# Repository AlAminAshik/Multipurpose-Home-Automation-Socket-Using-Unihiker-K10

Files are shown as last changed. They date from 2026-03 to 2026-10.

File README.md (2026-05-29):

# Multipurpose-Home-Automation-Socket-Using-Unihiker-K10
This repo contains all the coding and circuit diagram related to my home automation project using unihiker K10.

Important fix: I found a bug in the Unihikerk10.cpp code, for the readALS() function. It uses a ratio to calculate the light intensity (_ratio = _als_ch1/(_als_ch0+_als_ch1);) At complete darkness both ch0 and ch1 can become 0 and the ratio becomes 0/0 which causes device to reset. Fix is to add a number with the denominator (_ratio = _als_ch1/(_als_ch0+_als_ch1+1))



Imagine controlling your light, fan, alarm, and even AC using voice without the need for wifi or a phone.

In this project, I will describe in detail all the processes of making such a device. The 3d printed enclosure fits perfectly on the wall, and connecting to the outlet is super easy.

## The device currently features:
* Voice commands to perform various tasks. (with dual mic)
* Appliance control using TRIAC (1 Fan with dimmer, and 1 Light)
* Appliance control using Infra-Red (1 AC by cloning signal)
* Alarm clock page.
* Four touch sensitive buttons.
* A 2.8-inch color LCD screen.
* Wifi synced Clock.
* Temperature, Humidity, and Light Intensity Measurement.
* Auditory feedback.
* Mobile phone/webpage control (future implementation)

## Components used:
* 1 x UNIHIKER K10 AI Coding Board LINK
* 4 x Capacitive Touch Switch TTP223B LINK
* 4 x 15pF capacitors.
* 1 x USB Samsung adapter 5V 2A
* 1 x 5mm IR LED LINK
* 2 x BT134-600E 4A TRIAC
* 1 x MOV 471k LINK
* 2 x 275V 0.1uF suppression capacitor LINK
* 2 x 0.1uF 450V 104k LINK
* Some resistors and wires

# What it does?

I wanted to make a very practical project. With that in mind, I added multiple features. They are:

### Two Pages:
* Home page
    - shows time, WiFi, appliance status, light intensity, humidity, temperature, alarm time status.
    - Responds to the four buttons:
        - Alarm button:
            - short press: Switches between fan speeds (0 to 4), and stops the alarm if ringing.
            - long press: switches to the alarm page.
        - AC button:
            - short press: Toggles AC ON and OFF with a single press.
        - Fan button:
            - short press: Toggles Fan ON and OFF with a single press.
        - Light button:
            - short press: Toggles Light ON and OFF with a single press.
    - Responds to voice commands:
        - Voice command "Show Alarm": switches to the alarm page.
        - Voice command "Hide Alarm": switches to the main page.
        - Voice command "Fan" : Toggles fan ON and OFF.
        - Voice command "Lights": Toggles light ON and OFF.
        - Voice command "AC": Toggles AC ON and OFF.
        - Voice command "Fan Full speed": sets fan speed to max speed.
        - Voice command "Fan low speed": set the fan speed to the lowest speed.

* Alarm page (24 hour format)
    - shows time, WiFi, alarm logo, alarm time, alarm status, and button functions.
    - Responds to the four buttons:
        - Alarm button:
            - short press: stops the alarm if ringing.
            - long press: switches to the Home page.
        - AC button:
            - short press: Toggles alarm On and OFF.
        - Fan button:
            - short press: increments the minute hand.
        - Light button:
            - short press: increments the hour hand.
    - Responds to voice commands: Same as Home page.

# 3D Files
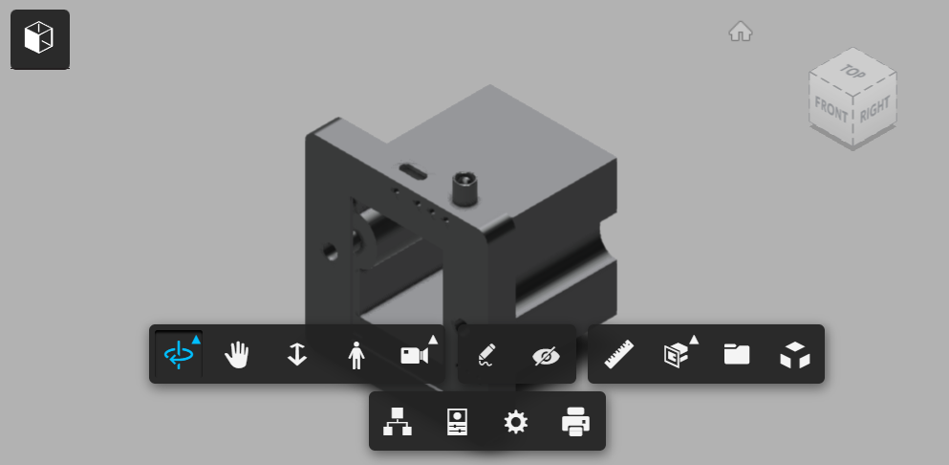
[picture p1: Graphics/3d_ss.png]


The 3d structure is made using Fusion360, you can get the file from this link: https://a360.co/4cmEmkP

# The code
The code is located at "Main Code/src/main.cpp". The code has some header file dependency that are located at "Main code/include".
[]Additional two file, the IRRecvDump.cpp code was used to find the raw infra red data from my AC remote control and IRSendBasic.cpp was used to generate and test if my AC properly responds to signal. These two files were not a part of the main code.

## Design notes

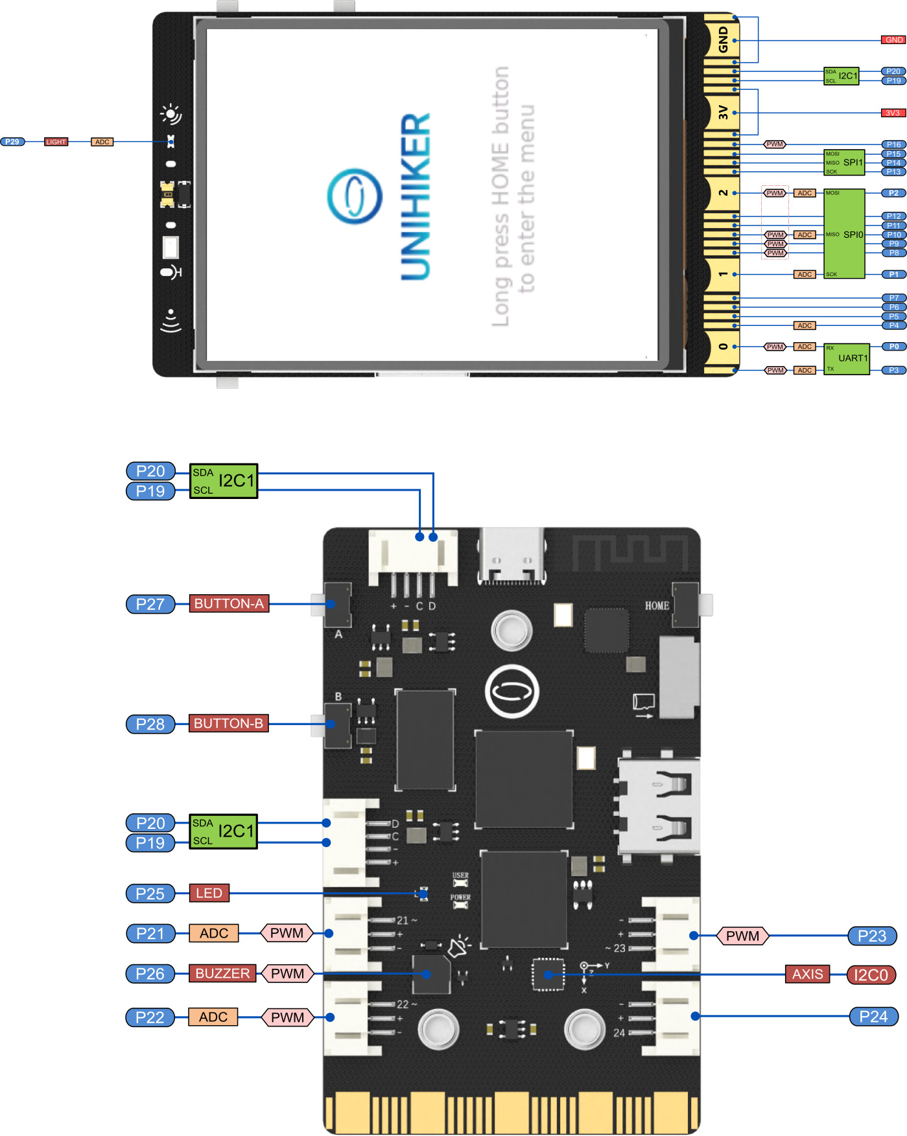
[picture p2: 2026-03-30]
UniHiker-pinout-diagram.jpg

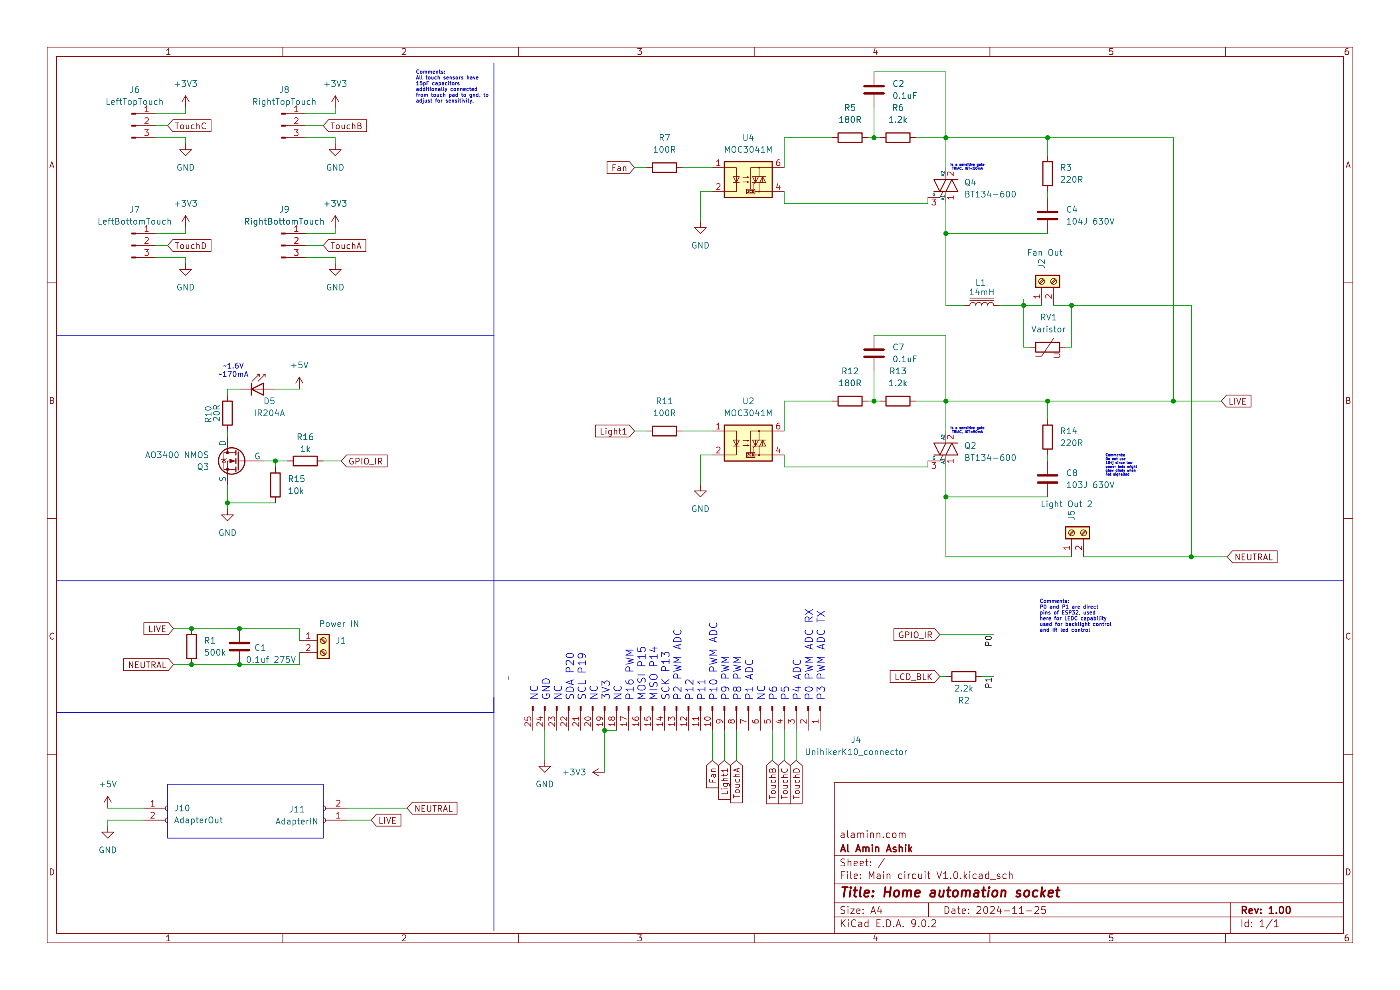
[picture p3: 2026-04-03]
circuit/Main circuit V1.0/Main circuit V1.0.png

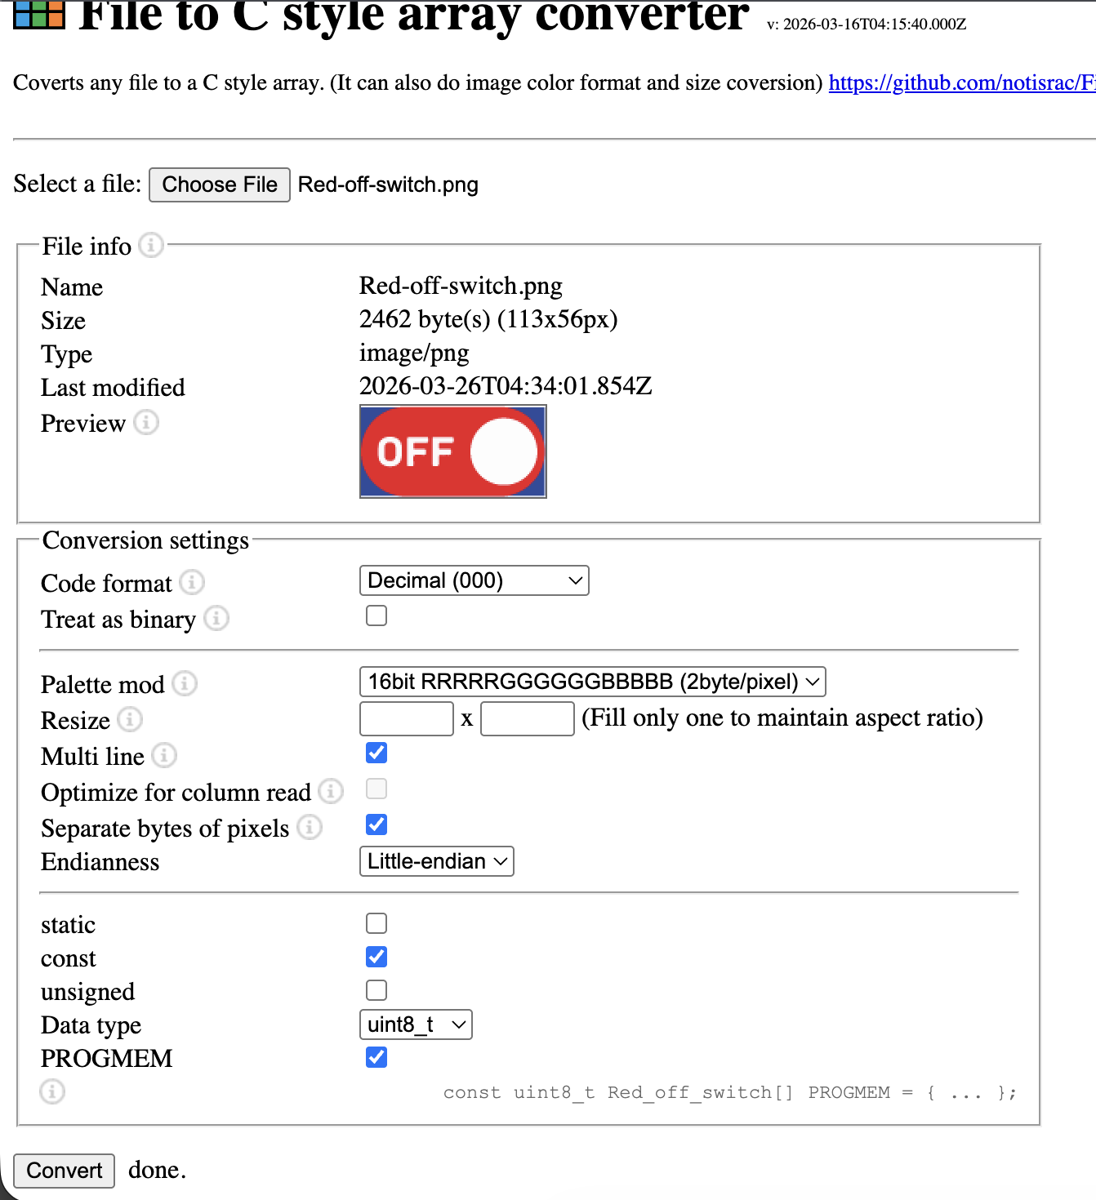
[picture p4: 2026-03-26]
Graphics/parameters to generate c code from image unihiker k10.png

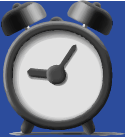
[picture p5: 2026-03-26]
Graphics/alarmclock.png

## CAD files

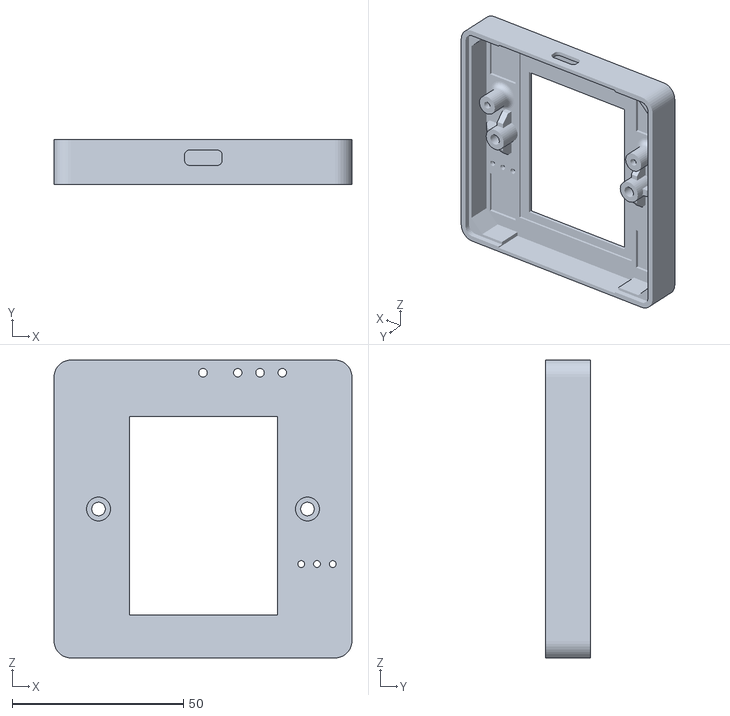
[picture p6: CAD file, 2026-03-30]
3D files/main body front.stl
87.0 x 13.0 x 87.0

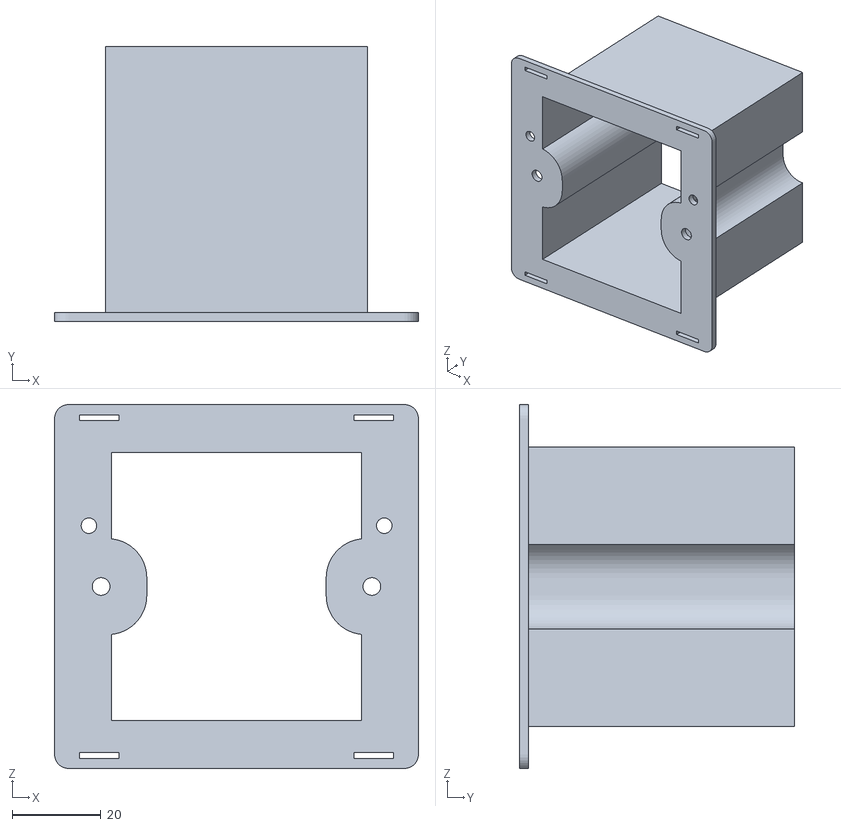
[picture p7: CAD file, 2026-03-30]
3D files/Main body body.stl
82.0 x 62.0 x 82.0

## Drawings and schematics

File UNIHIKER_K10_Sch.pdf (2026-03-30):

11

22

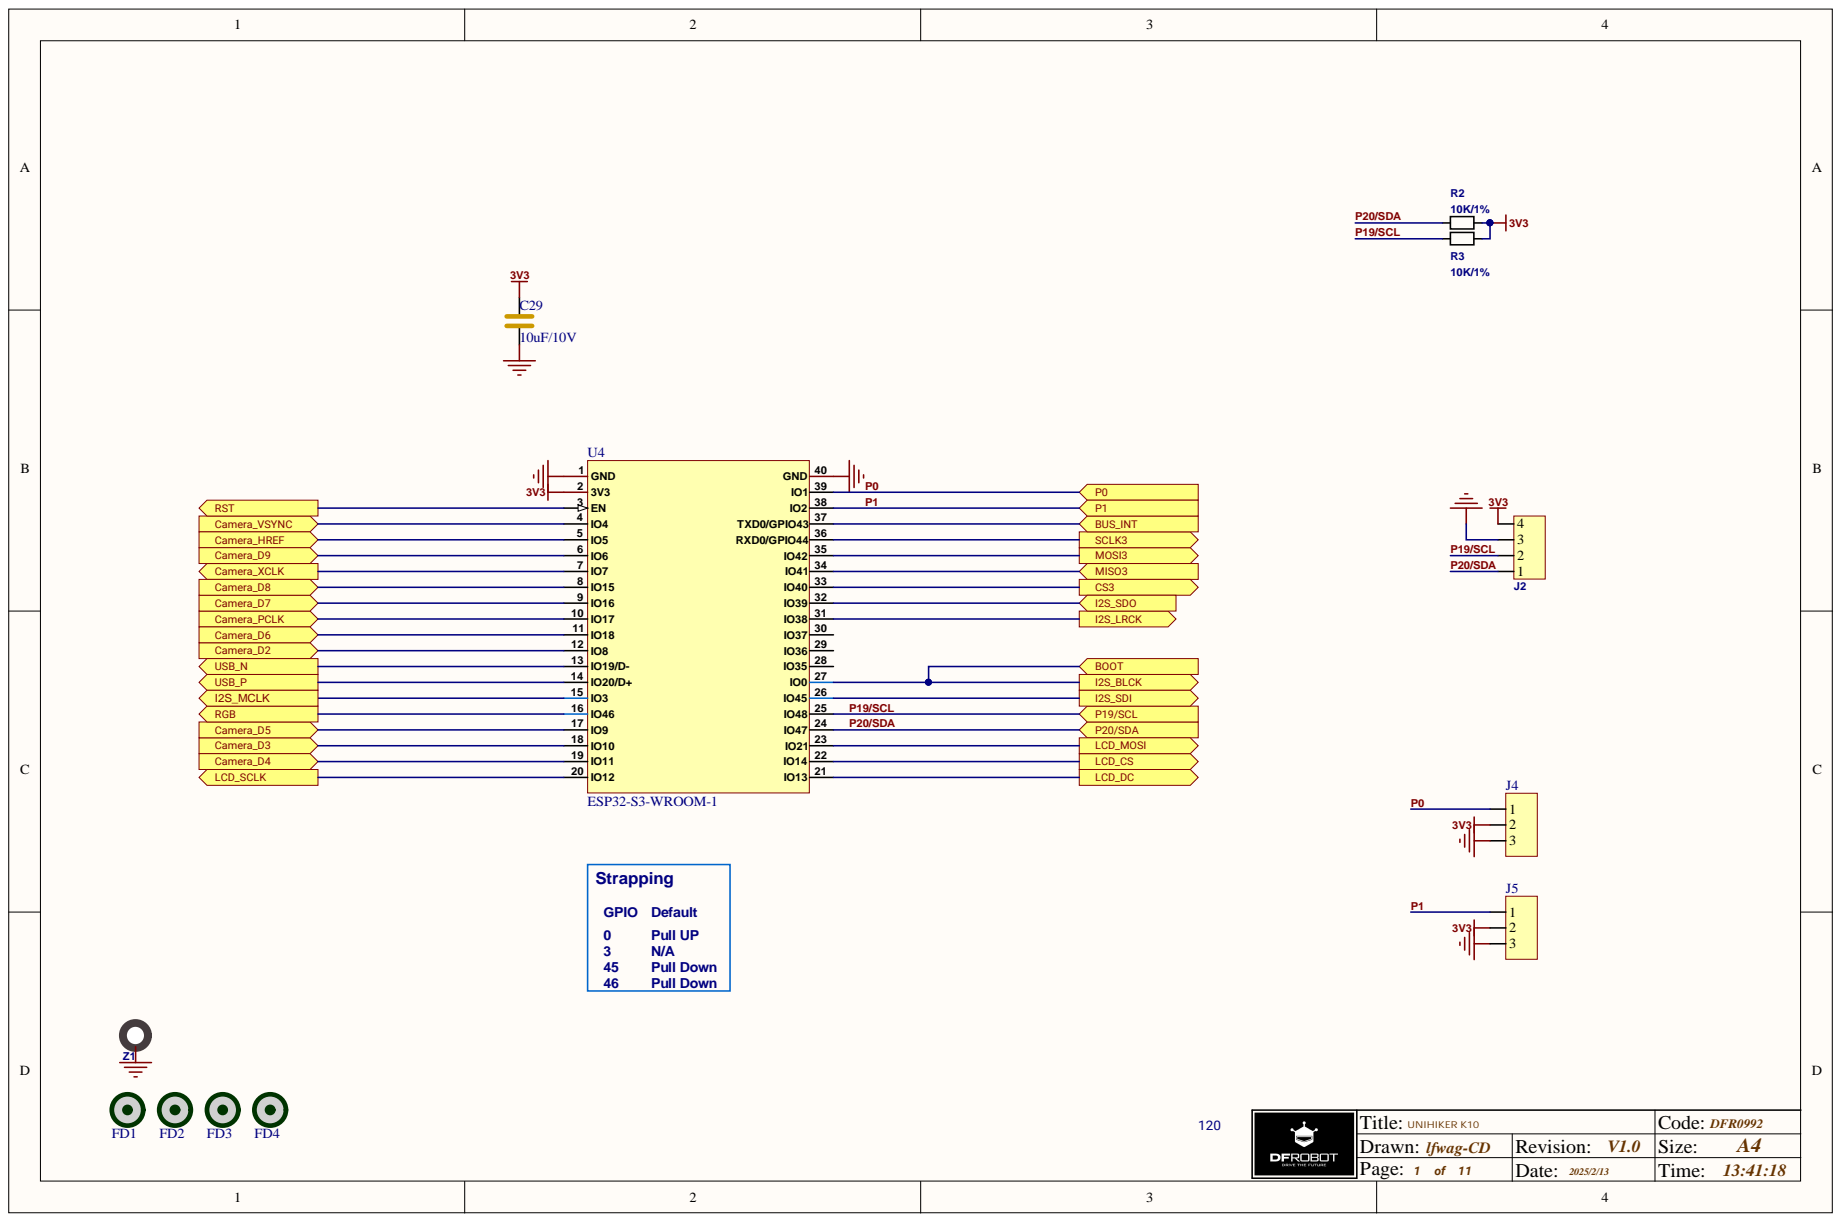
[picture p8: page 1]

A | A

## POP0

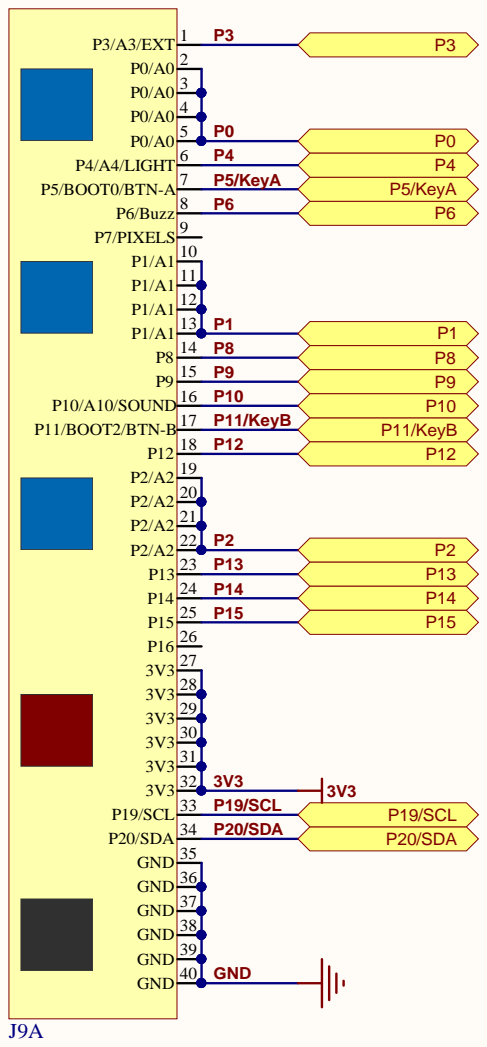
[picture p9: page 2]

11

22

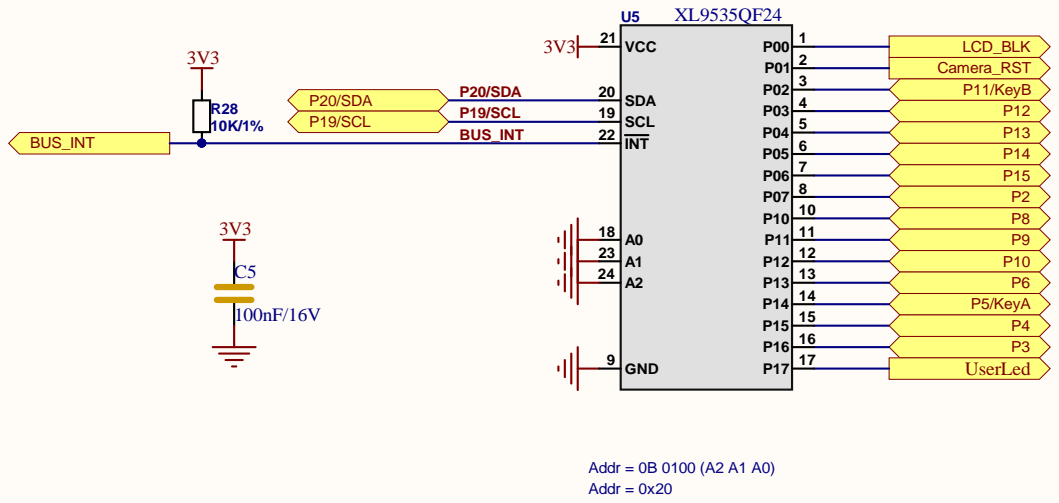
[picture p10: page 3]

A | A

## BOOT

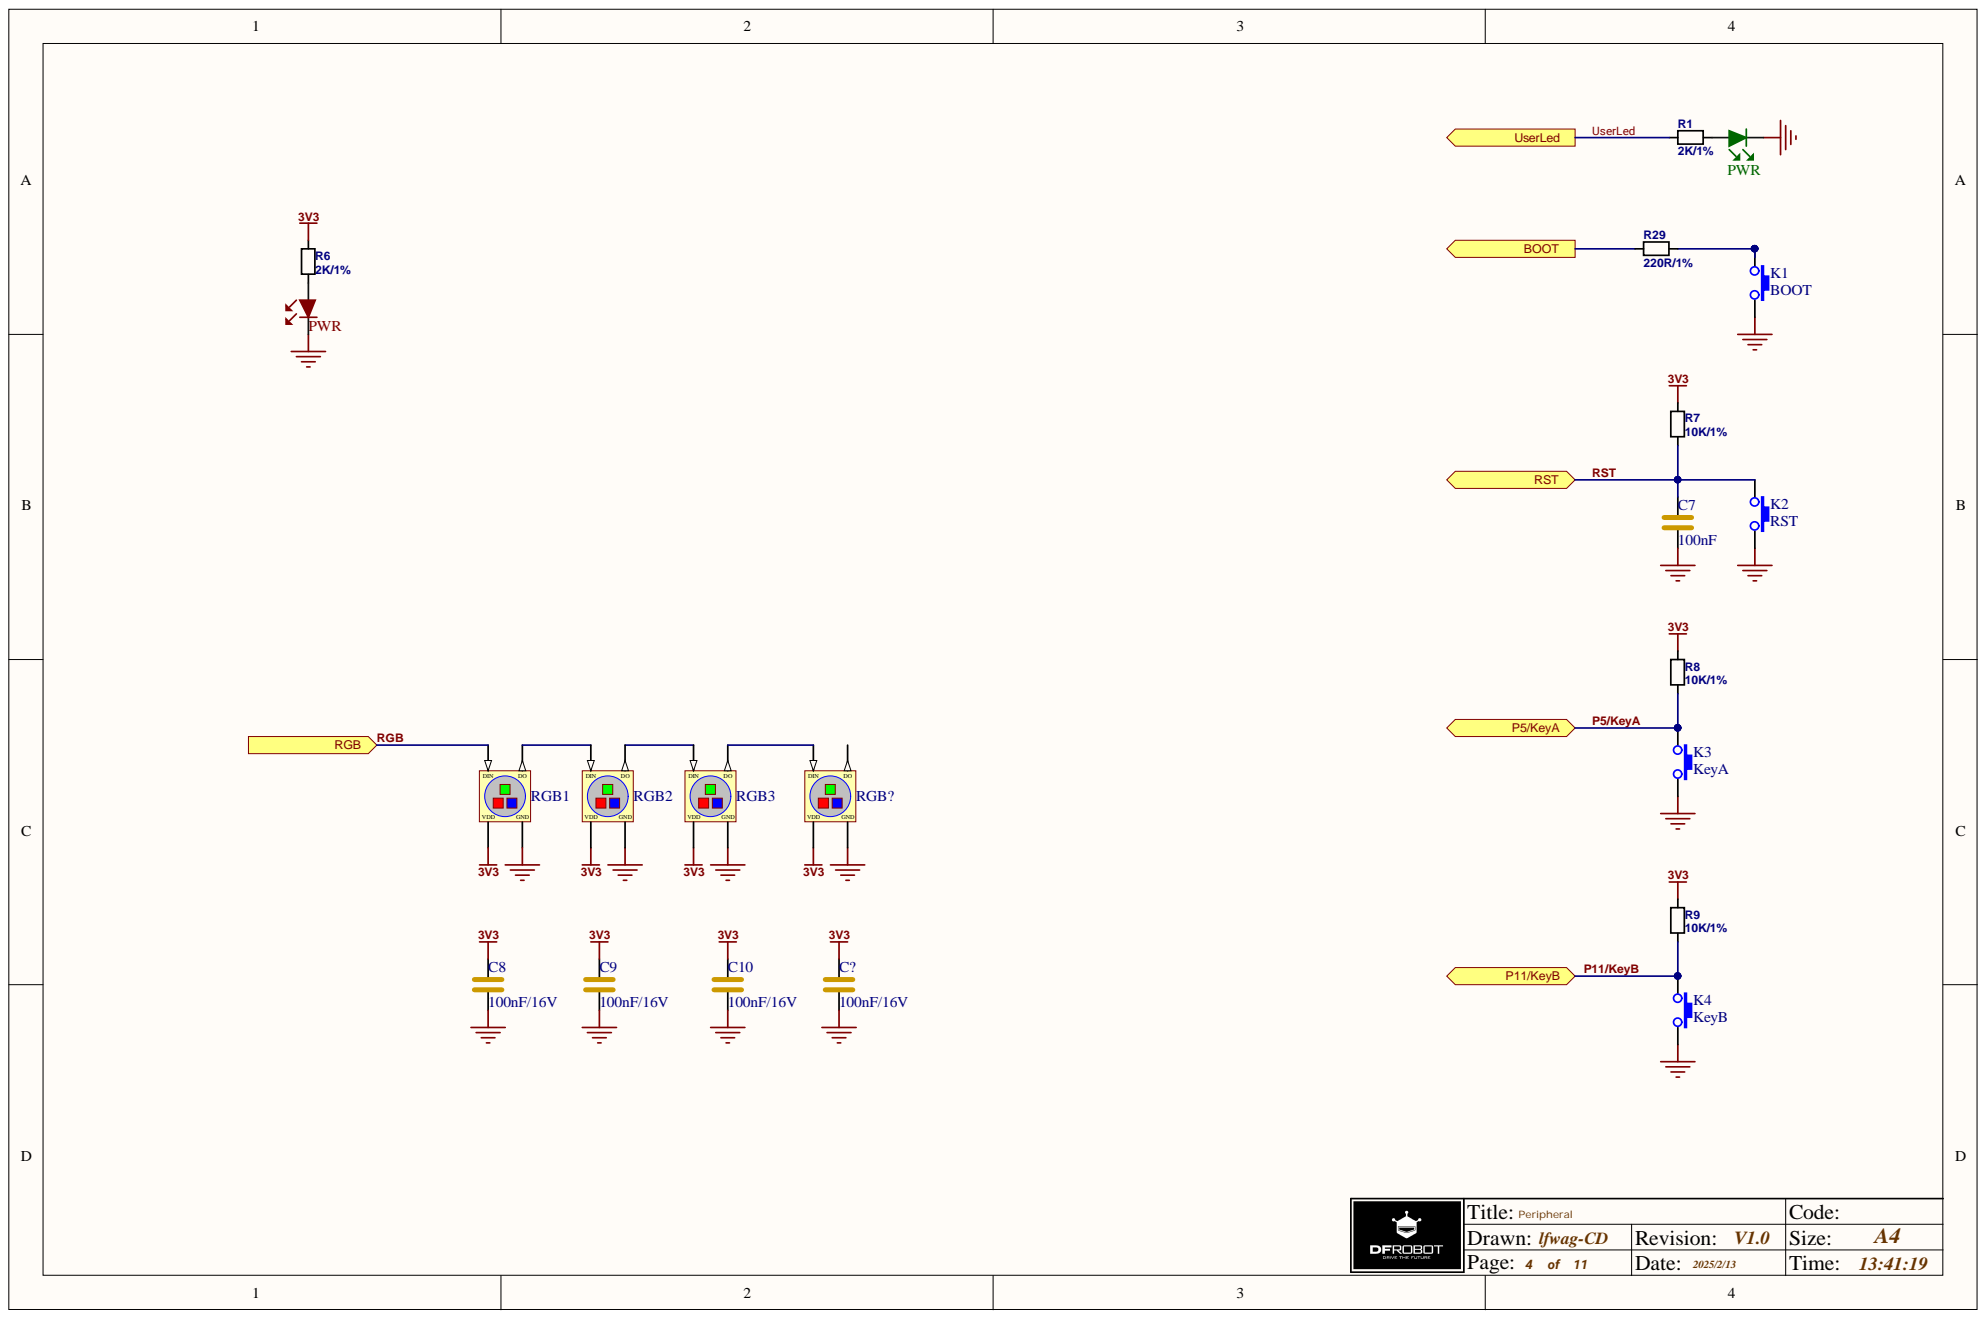
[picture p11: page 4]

11

22

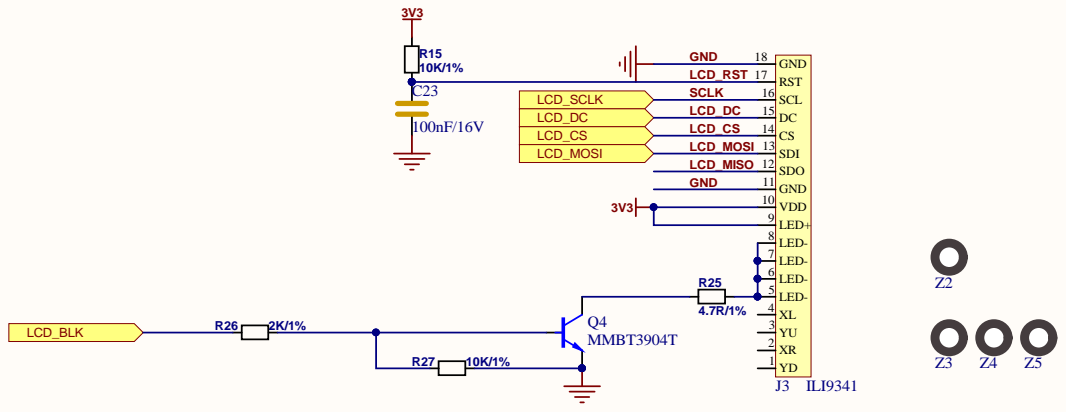
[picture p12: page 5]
LCD lfwag-CD; Title; : Drawn: Page:; Code; Size; vision:; GND; LCD_RS; SCL K; LCD_DC; LCD_CS; LCD_MOS I; LCD_M I; _MOS I; ILI; LED-; MBT

5 LED- 6 LED- 7 LED- 8 LED+ 9 VDD 10 RST 17 GND 18
GND 11 SDO 12 SDI 13 CS 14 DC 15 SCL 16

A | A
U8 | ES7243E

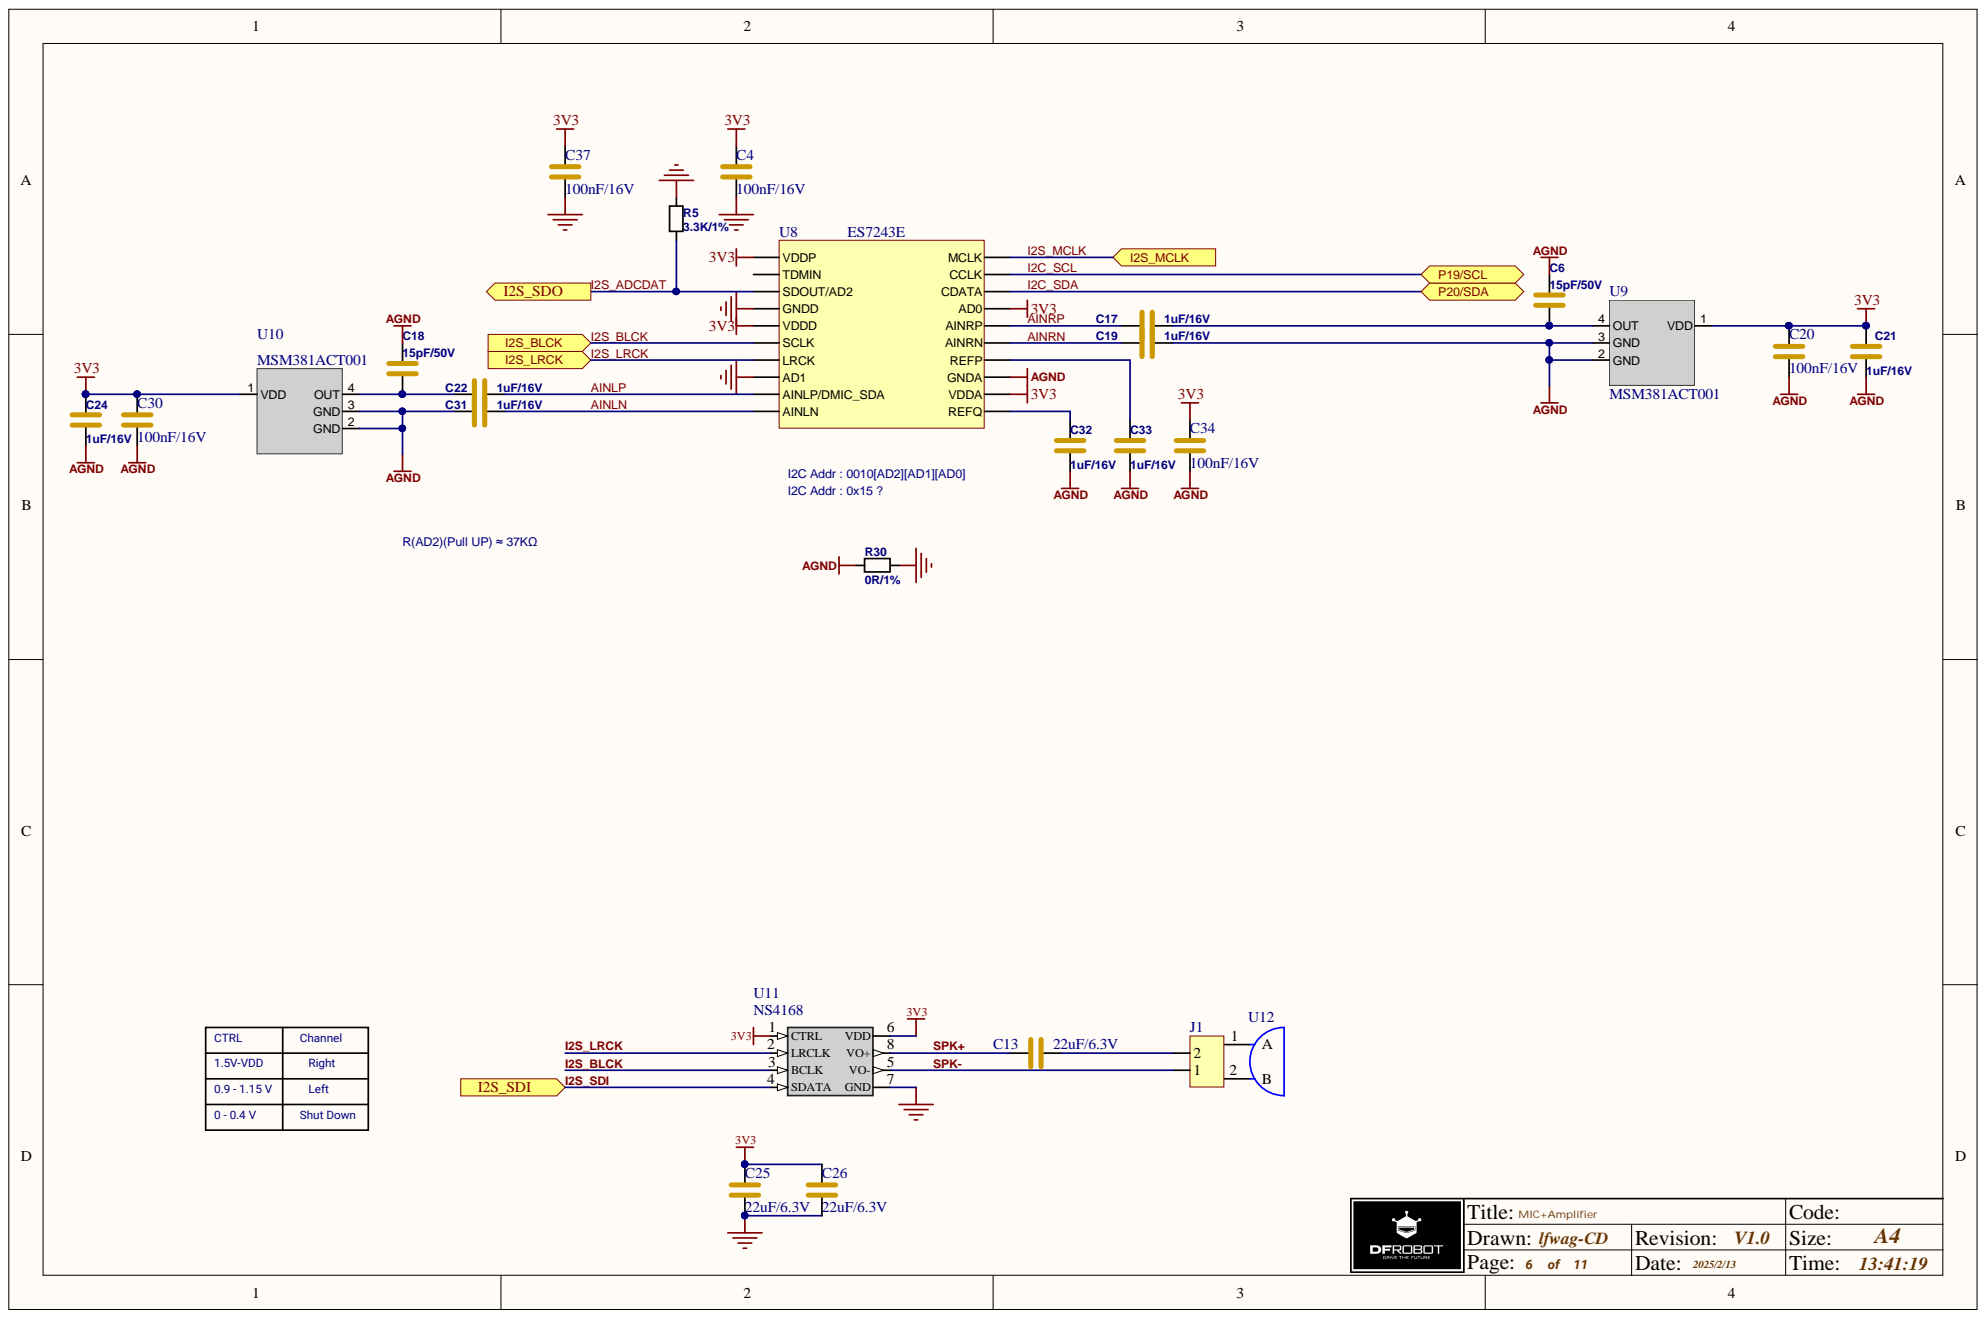
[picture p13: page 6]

11

22

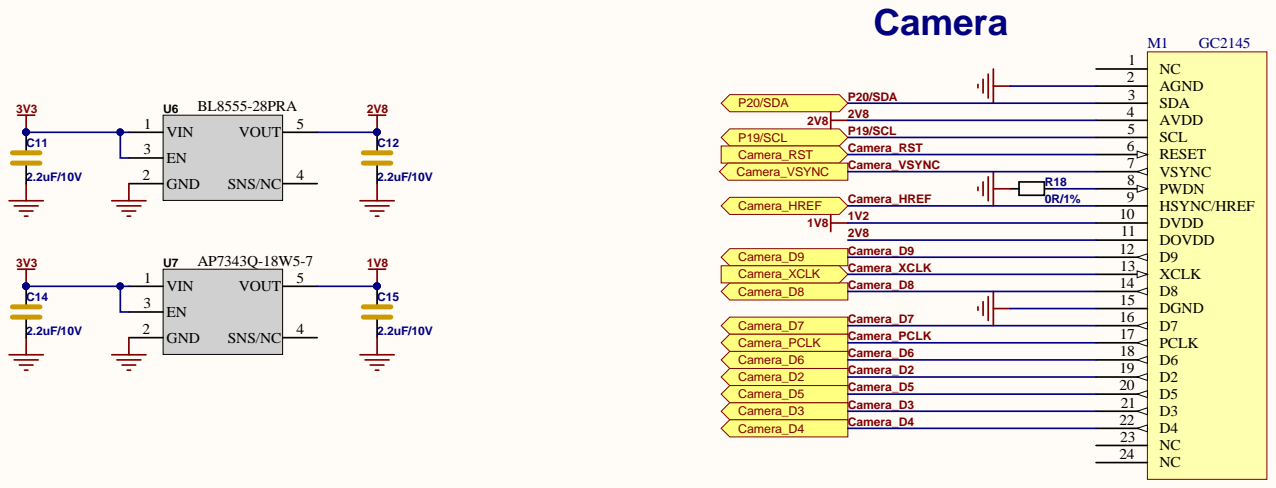
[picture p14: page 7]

A | A

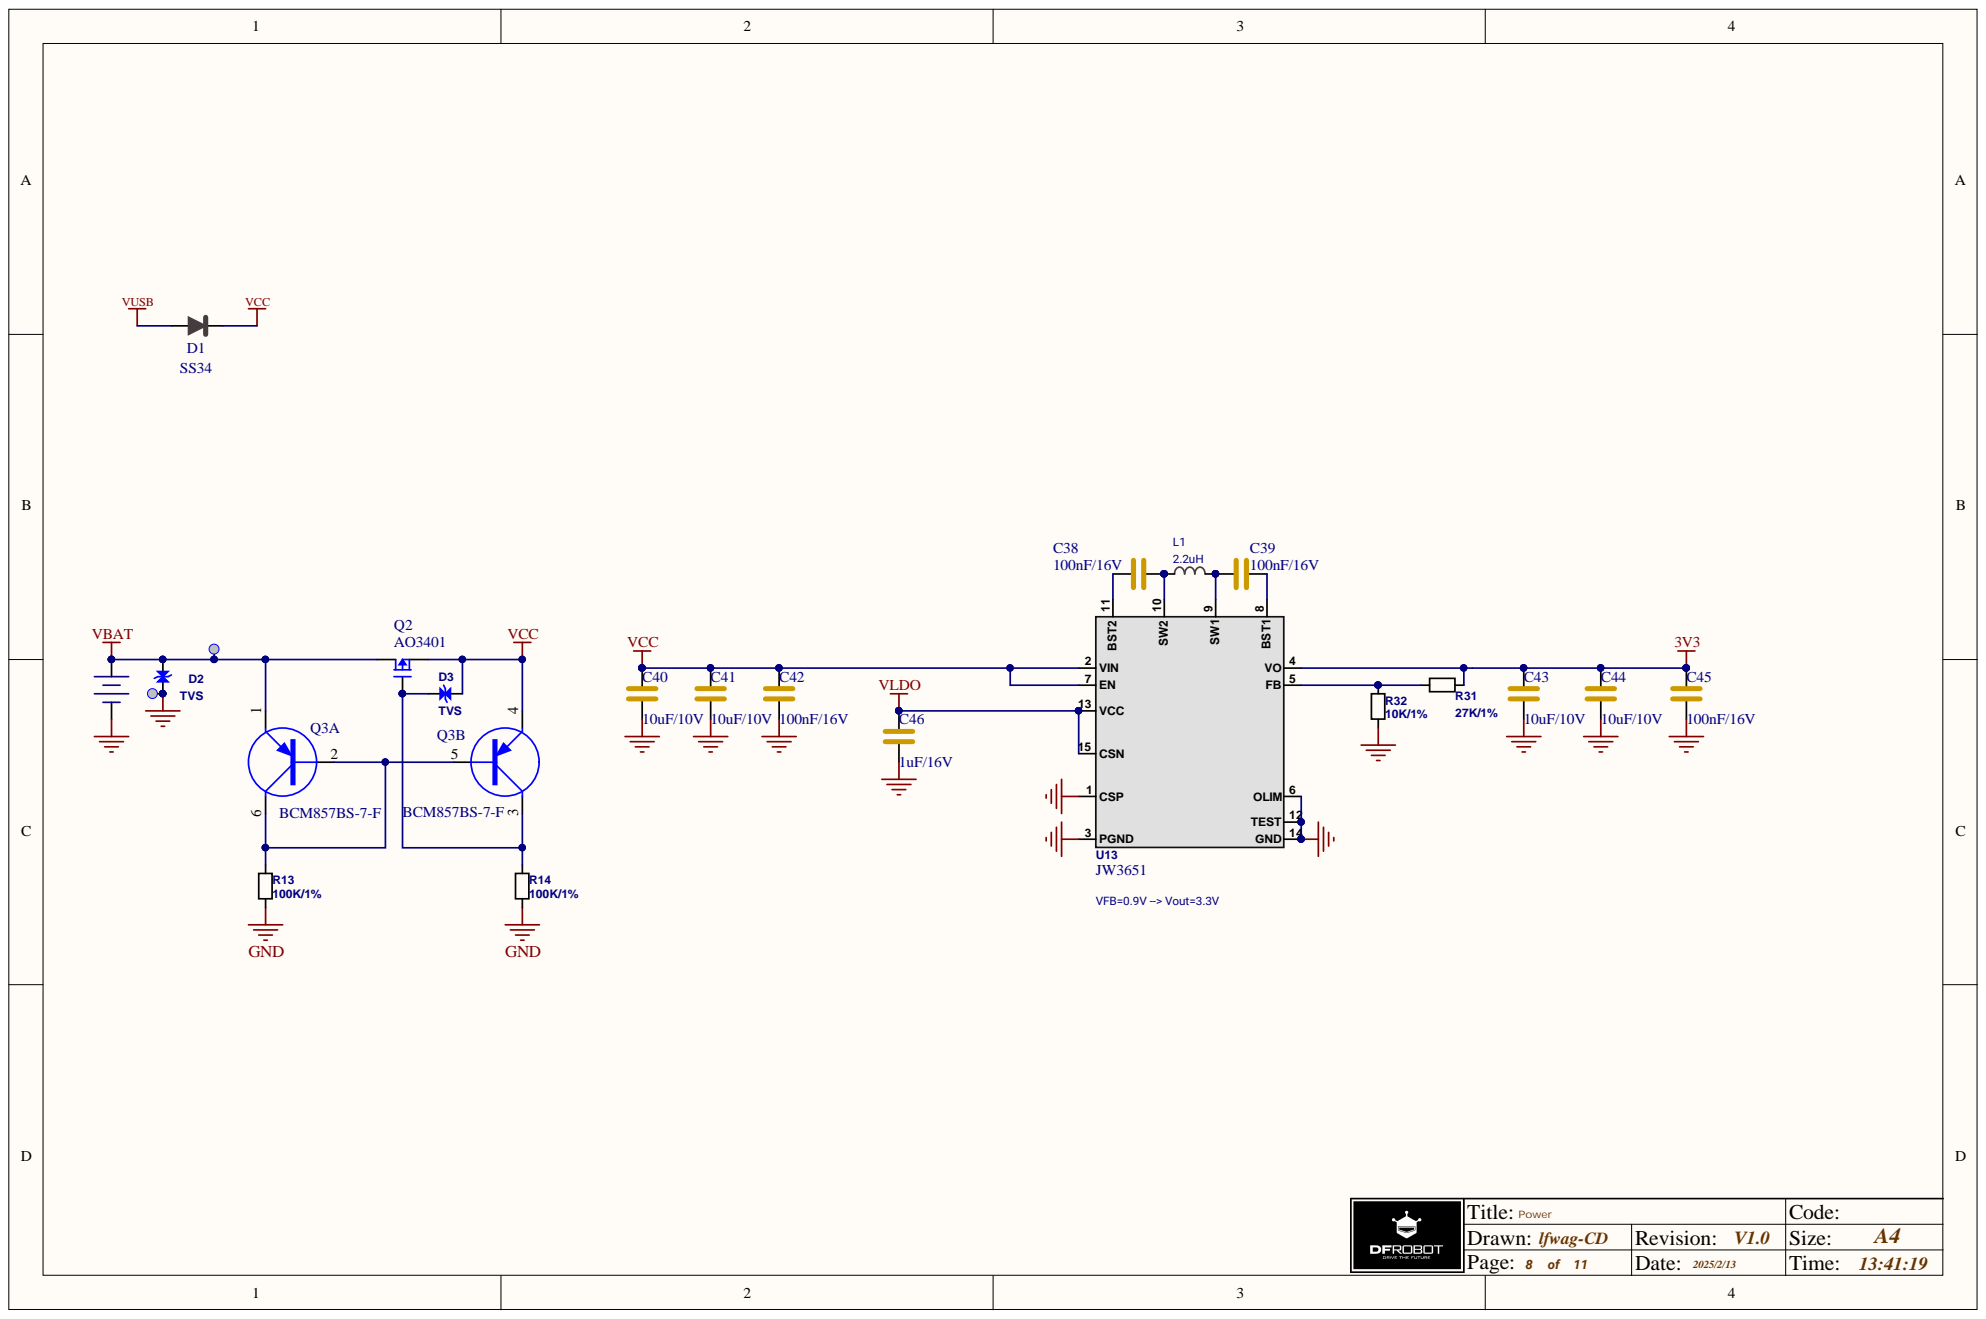
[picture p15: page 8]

A | A

M2

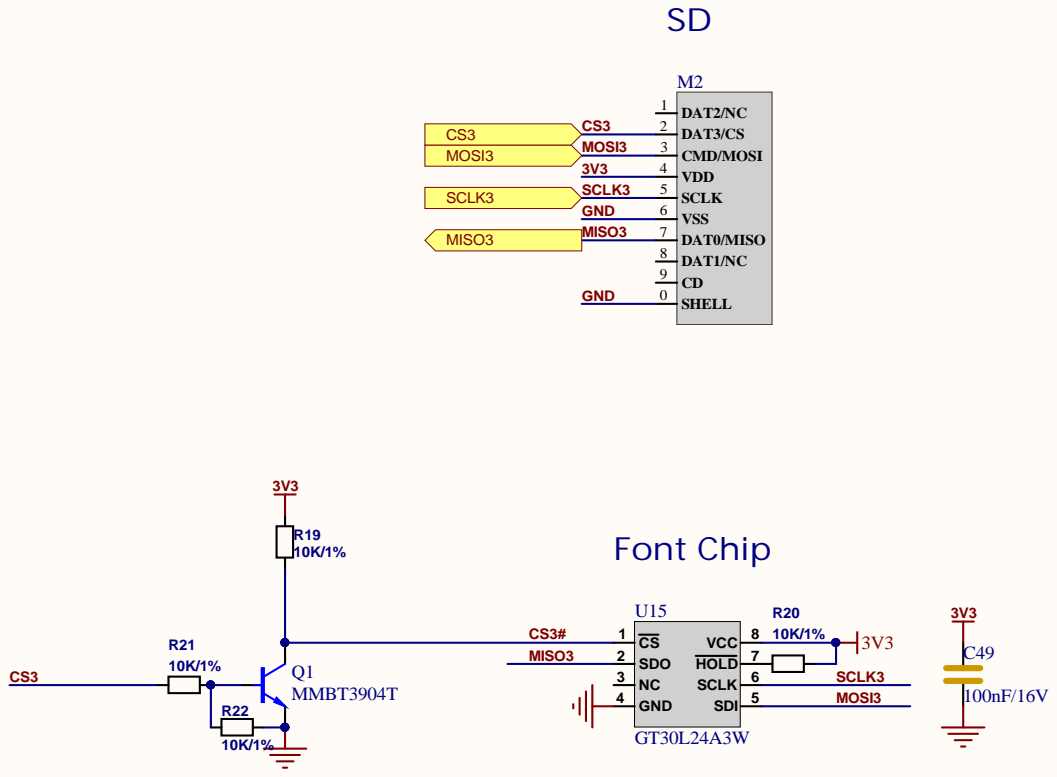
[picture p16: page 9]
Title: Drawn:; Code: Size:; Revision: V1.0; DAT2/NC 1; DAT3/CS 2; CMD/MOSI 3; VDD 4; SCLK 5; VSS 6; DAT0/MISO 7; DAT1/NC 8; SHELL 0; MOSI3; SCLK3; GND; MISO3; SDO 2; GND 4; SDI 5 SCLK 6 HOLD 7 VCC 8; Font Chip; MMBT3904T

TF Card & Font Chip
lfwag-CD

A | A

## AHT20

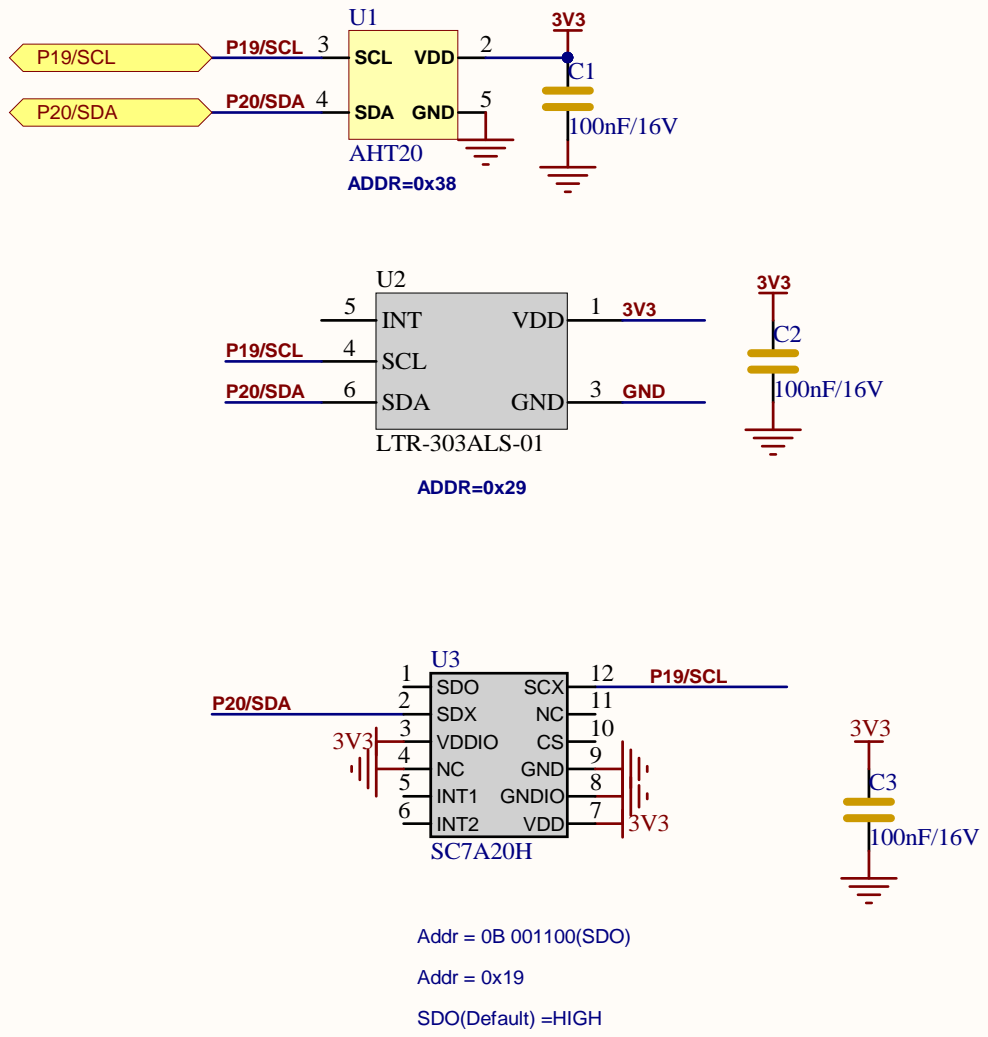
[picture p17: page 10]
I2C slave lfwag-CD; Title: Drawn:; Code: Size:; Revision: V1.0; VDD; 2 SCL 3; SDA 4; GND; P19/SCL; P20/SDA; ADDR=0x38; VDD 1; GND 3 SDA 6; SCL 4; INT 5; LTR-303ALS-01; ADDR=0x29; SDO 1; SDX 2 VDDIO 3 NC 4 INT1 5; INT2 6; 7 GNDIO; 8 GND; 11 SCX; Addr = 0B 001100(SDO); Addr = 0x19

SDO(Default) =HIGH

11

22

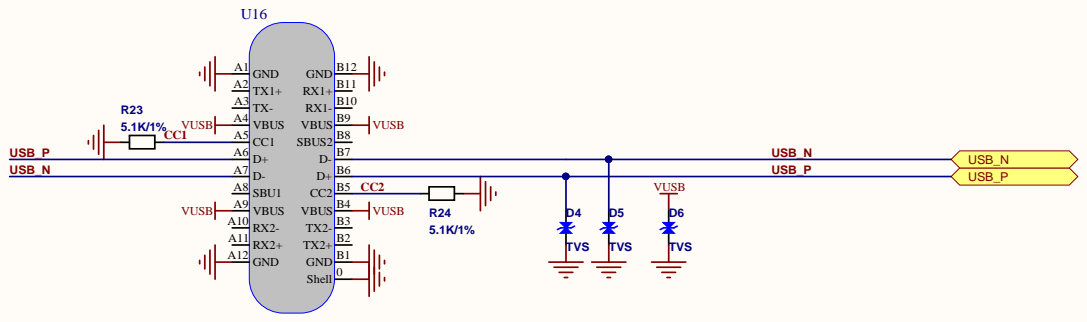
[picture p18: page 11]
USB lfwag-CD; Title; : Drawn: Page:; Code; Size; vision:; GND A1; GND A12; GND; USB_P; USB_N; USB _

1 TX2+ B2 TX2- B3 VBUS B4 CC2 B5 D+ B6 D- B7 SBUS2 B8 VBUS B9 RX1- B10 RX1+ B11 GND B12 Shell 0

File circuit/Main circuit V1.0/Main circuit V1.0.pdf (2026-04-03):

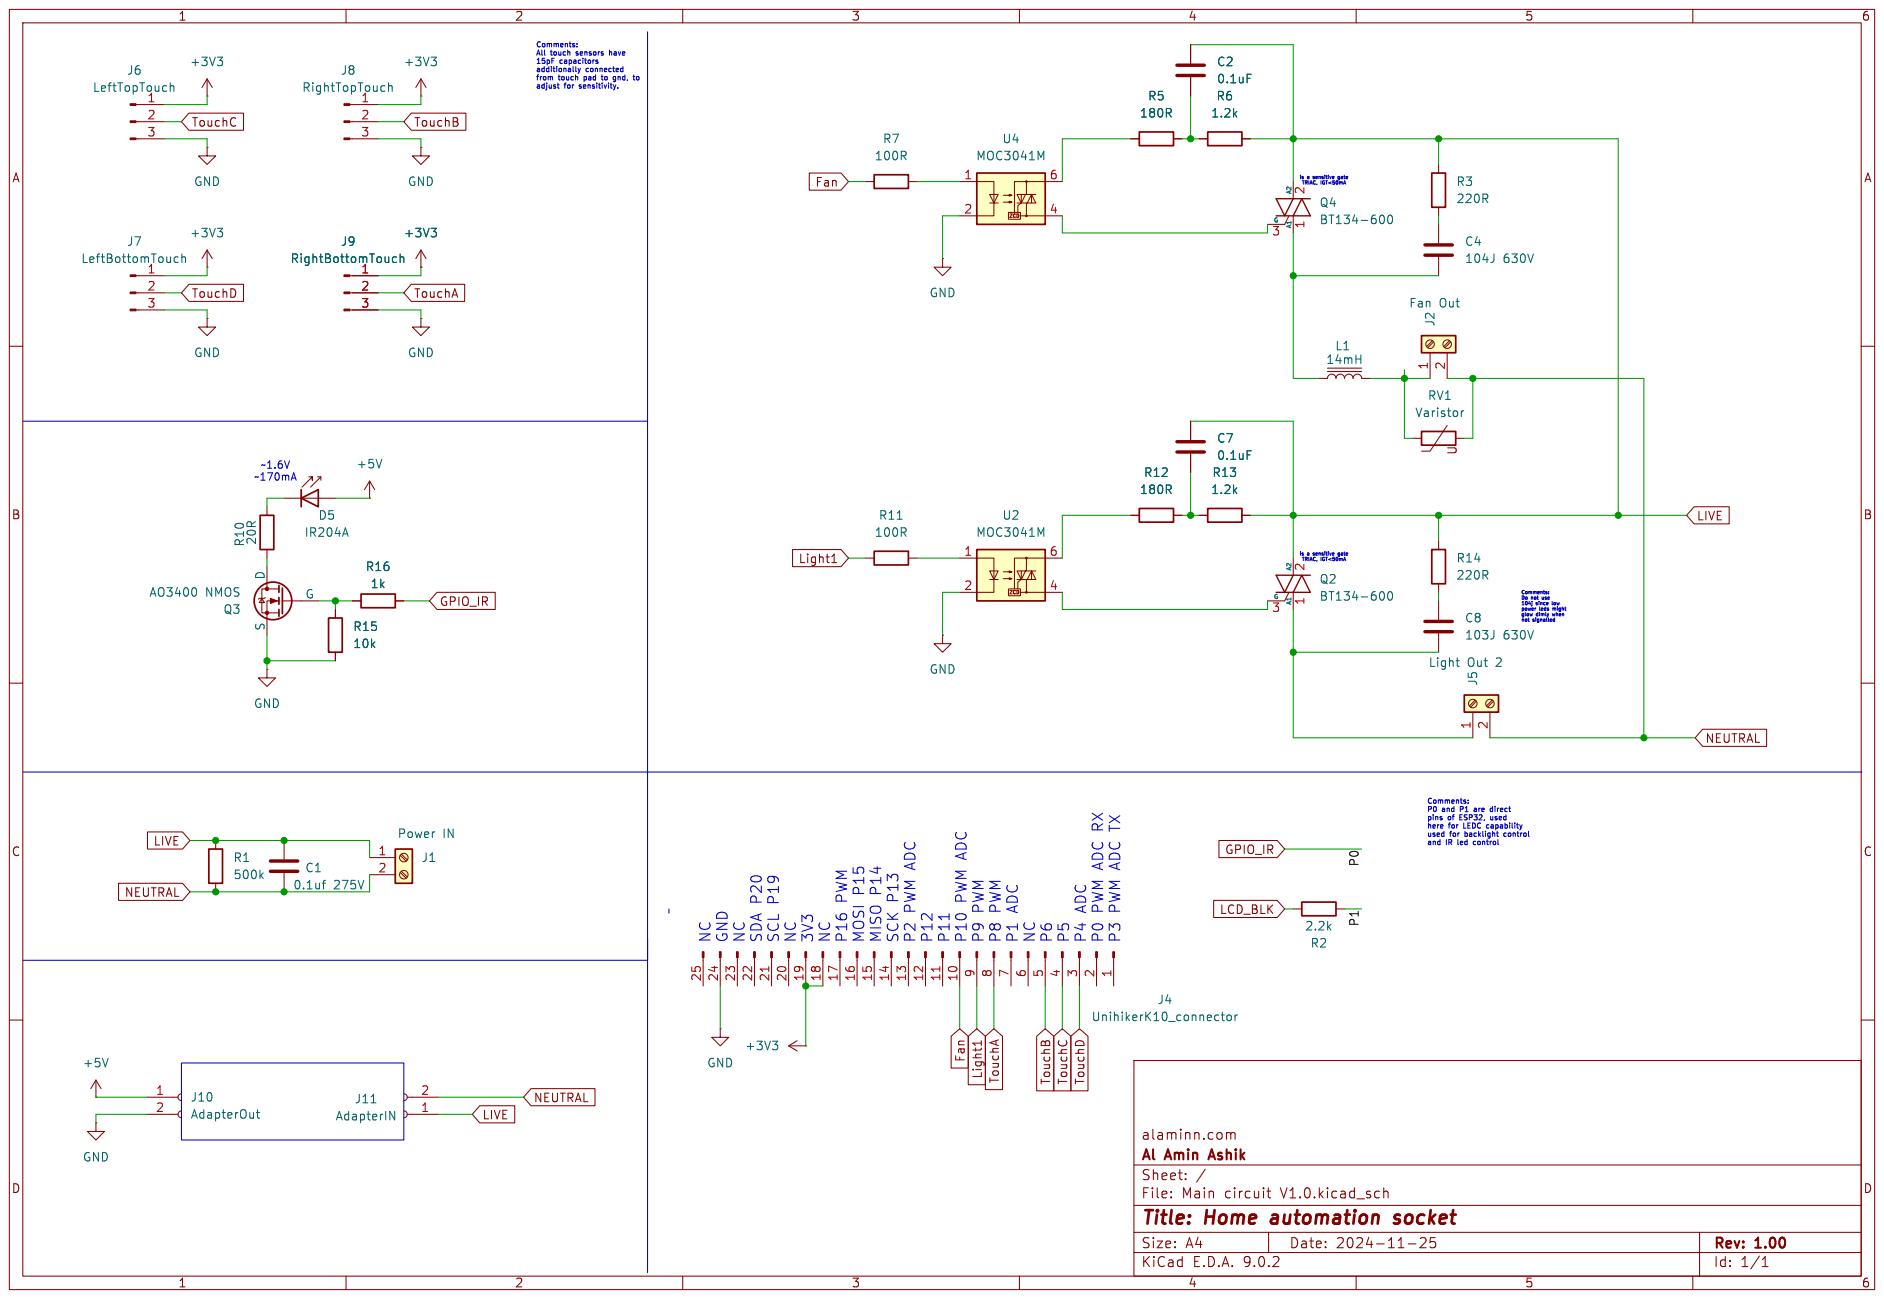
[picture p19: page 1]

from touch pad to gnd, to

Comments: Do not use
not signalled

Comments: P0 and P1 are direct pins of ESP32, used

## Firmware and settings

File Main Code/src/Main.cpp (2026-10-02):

#include "unihiker_k10.h"
#include <IRsend.h>
#include "asr.h"
#include <WiFi.h>
#include <WiFiClient.h>
#include <WiFiClientSecure.h>
#include <WiFiManager.h>
#include <time.h>
#define sensor_t adafruit_sensor_t
#include <Adafruit_AHTX0.h>
#undef sensor_t
#include "RedOffSwitchIcon.h"
#include "GreenOnSwitchIcon.h"
#include "alarmLogo.h"
#include "noWifiIcon.h"
#include "wifiIcon.h"
#include "lightIcon.h"
#include "fanIcon.h"
#include "ACIcon.h"

Adafruit_AHTX0 aht;
WiFiManager wm;

#define WIFI_SSID       "Amin Residence"
#define WIFI_PASS       "alamiralif86"
#define WIFI_SSID_DEBUG "Smart Socket by Alamin"
#define WIFI_PASS_DEBUG "87654321"

// Backlight and display ─────────────────────────────────────────────────────────────────────────────
UNIHIKER_K10 k10;
uint8_t screen_dir = 2;
uint16_t lightIntensity;
#define BackLED P1  //this pin was soldered with the backled transistor of the display since eLCD_BLK pin interferes with the voice
int minLightIntensity = 2; // less than 2 lux the screen with turn off
int maxLightIntensity = 15; // more than 15 lux the screen will be at full brightness

ASR   asr;
Music music;

// IR Data ─────────────────────────────────────────────────────────────────────────────
const uint16_t kIrLed = P0; // this pin was soldered with the IR LED on the back of the board
IRsend irsend(kIrLed);
uint16_t AC_ONrawData[197]  = {6058, 7340,  608, 1684,  586, 1684,  584, 1682,  586, 1682,  586, 1682,  584, 1684,  586, 1684,  586, 1682,  586, 564,  586, 566,  582, 568,  584, 566,  584, 566,  584, 566,  584, 564,  586, 566,  582, 1684,  584, 1686,  582, 1684,  584, 1684,  582, 1688,  582, 1684,  584, 1686,  582, 1684,  584, 566,  586, 564,  582, 566,  584, 574,  576, 566,  584, 574,  576, 566,  584, 566,  586, 1684,  582, 1692,  578, 1682,  586, 1682,  584, 1684,  584, 1682,  584, 1684,  584, 1684,  586, 564,  584, 566,  586, 564,  586, 566,  584, 568,  584, 564,  584, 566,  586, 564,  582, 1688,  584, 564,  586, 564,  586, 1684,  584, 564,  586, 564,  586, 562,  586, 1682,  586, 564,  586, 1684,  584, 1684,  582, 566,  582, 1686,  588, 1680,  558, 1710,  586, 564,  584, 1686,  582, 1684,  584, 576,  576, 568,  580, 1686,  586, 564,  584, 1684,  582, 1684,  584, 568,  586, 564,  584, 1684,  584, 1684,  586, 562,  586, 1684,  582, 566,  586, 564,  586, 564,  586, 1684,  584, 564,  584, 1692,  574, 568,  586, 1682,  584, 568,  584, 1682,  586, 1684,  584, 566,  586, 1684,  584, 566,  582, 1686,  582, 566,  584, 1684,  584, 564,  586, 7386,  586};
uint16_t AC_OFFrawData[197] = {6094, 7330,  618, 1654,  620, 1650,  614, 1650,  620, 1654,  616, 1652,  616, 1650,  618, 1650,  618, 1650,  616, 536,  614, 536,  616, 536,  614, 538,  612, 536,  614, 534,  616, 536,  614, 536,  616, 1654,  614, 1650,  616, 1654,  616, 1654,  614, 1652,  616, 1654,  616, 1652,  612, 1658,  612, 534,  616, 534,  616, 538,  586, 562,  612, 538,  612, 536,  612, 540,  610, 536,  614, 1652,  616, 1652,  614, 1656,  612, 1654,  614, 1654,  616, 1652,  616, 1654,  614, 1650,  616, 536,  614, 536,  616, 534,  616, 534,  614, 534,  616, 536,  614, 534,  616, 536,  614, 1656,  614, 1654,  612, 536,  616, 1654,  612, 538,  614, 534,  616, 536,  614, 1654,  616, 536,  612, 536,  616, 1652,  612, 536,  588, 1682,  612, 1656,  612, 1654,  588, 566,  610, 1654,  612, 1658,  612, 540,  612, 538,  612, 1656,  612, 536,  586, 1684,  612, 1652,  612, 538,  616, 538,  610, 1654,  614, 1656,  612, 538,  614, 1654,  614, 536,  614, 536,  612, 536,  614, 1656,  612, 538,  612, 1654,  616, 536,  610, 1660,  612, 538,  612, 1652,  618, 1652,  614, 538,  612, 1656,  612, 536,  616, 1652,  614, 536,  614, 1652,  616, 536,  614, 7354,  618};

// ── Button & output pins ──────────────────────────────────────────────────────
#define LeftTopButton     eP5_KeyA
#define LeftBottomButton  eP4
#define RightTopButton    eP6
#define RightBottomButton eP8
#define TriacLight        eP9
#define TriacFan          eP10
//#define BaclLED           eLCD_BLK    //using this pin blocks voice, idk why
uint8_t fanSpeed = 4; // fan speed changes from 0 to 4

// ── Page enum ─────────────────────────────────────────────────────────────────
enum Page { PAGE_MAIN, PAGE_ALARM};
static volatile Page currentPage = PAGE_MAIN;
int pageSwitchPressTime = 1000; // 1 second press on the mode button changes to next page

// Alarm state ───────────────────────────────────────────────────────────────
static volatile int  alarmHour    = 6;  // default alarm time 6:00 AM, can be changed via buttons on the alarm page
static volatile int  alarmMinute  = 0;
static volatile bool alarmEnabled = true;
static volatile bool alarmFired   = false;
static volatile bool alarmRunning = false;
// Local variable to track whether we already started the alarm sound
static bool alarmSoundActive = false;
// Alarm timeout
int alarmDurationMins = 60; // 60 minutes

// Shared appliance state ────────────────────────────────────────────────────
static volatile bool TriacLightState = false;
static volatile bool TriacFanState   = false;
static volatile bool ACState         = false;

// Semaphores / mutexes ──────────────────────────────────────────────────────
static SemaphoreHandle_t stateMutex = NULL;  // protects appliance states + page
static SemaphoreHandle_t irMutex    = NULL;  // protects irsend
static SemaphoreHandle_t AlarmMutex = NULL;  // protects alarm state
static SemaphoreHandle_t DisplayMutex = NULL; // protects display brightness
uint8_t duty; // current backlight duty cycle (0-255)

//Page-change tracking (UI task only, no mutex needed) ─────────────────────
static volatile bool backgroundNeedsRedraw = true;   // force draw on first frame
uint32_t backGroundColor = 0x2C4C9C;


// ─────────────────────────────────────────────────────────────────────────────
// ─────────────────────────────────────────────────────────────────────────────
// ─────────────────────────────────────────────────────────────────────────────
void toggleLight() {
    xSemaphoreTake(stateMutex, portMAX_DELAY);
    TriacLightState = !TriacLightState;
    digital_write(TriacLight, TriacLightState ? HIGH : LOW);
    xSemaphoreGive(stateMutex);
}

// ─────────────────────────────────────────────────────────────────────────────
void toggleFan() {
    xSemaphoreTake(stateMutex, portMAX_DELAY);
    TriacFanState = !TriacFanState; //only triggers the RunFanSpeed active/inactive
    xSemaphoreGive(stateMutex);
}

void RunFanSpeed(uint8_t speed){
    static bool optoState = false;  //must be static
    uint16_t optoOnTime;  // Time optocoupler in on
    uint16_t optoOffTime;  // Time optocoupler is off 

    static unsigned long lastToggle = 0;
    unsigned long now = millis();

    switch (speed) {
        case 0: //off
            digital_write(TriacFan, LOW); // fully off
            return;
        case 1: //low
             optoOnTime = 200;
             optoOffTime = 300;  
            break;
        case 2: //medium
            optoOnTime = 300;
            optoOffTime = 200;
            break;
        case 3: //high
            optoOnTime = 400;
            optoOffTime = 120;
            break;
        case 4: //full on
            digital_write(TriacFan, HIGH);
            return;
    }
    long interval = optoState ? optoOnTime : optoOffTime;

    if (now - lastToggle >= interval && speed != 4) {
        lastToggle = now;
        optoState = !optoState;
        digital_write(TriacFan, optoState ? HIGH : LOW); // Toggle the fan state
    }
}

// ─────────────────────────────────────────────────────────────────────────────
void toggleAC() {
    xSemaphoreTake(stateMutex, portMAX_DELAY);
    bool newState = !ACState;
    xSemaphoreGive(stateMutex);

    xSemaphoreTake(irMutex, portMAX_DELAY);
    //suspend all other tasks on this code during transmission (very important)
    vTaskSuspendAll();
    if (newState) {
        irsend.sendRaw(AC_ONrawData,  197, 38);
        Serial.println("IR → AC ON");
    } else {
        irsend.sendRaw(AC_OFFrawData, 197, 38);
        Serial.println("IR → AC OFF");
    }
    xTaskResumeAll();
    xSemaphoreGive(irMutex);

    xSemaphoreTake(stateMutex, portMAX_DELAY);
    ACState = newState;
    xSemaphoreGive(stateMutex);
}

// ─────────────────────────────────────────────────────────────────────────────
void setBacklight(uint16_t lux) {
    xSemaphoreTake(DisplayMutex, portMAX_DELAY);
    if (lux < minLightIntensity) {
        duty = 0;           // display off
    } else if (lux >= maxLightIntensity) {
        duty = 255;         // full brightness
    } else {
        // linear ramp
        // minimum 50 (not 0) so the screen is always barely visible at lux=minLightIntensity
        uint32_t range = maxLightIntensity - minLightIntensity;
        uint32_t delta = lux - minLightIntensity;
        duty = (uint16_t)(50 + (delta * (255 - 50)) / range);
    }
    ledcWrite(BackLED, duty);
    xSemaphoreGive(DisplayMutex);
}

// ─────────────────────────────────────────────────────────────────────────────
// Helper – draws a vertical bar gauge using pipe characters
// minVal, maxVal = scale range
// label    = "Lux", "Hum", "Tmp"
// unit     = "%", "C", ""
// barHeight = total number of '|' characters at full scale
void drawVerticalBar(int x, int y, float value, float minVal, float maxVal, const char* label, const char* unit, int barHeight = 10) {
    // Clamp & compute how many filled bars
    float clamped = constrain(value, minVal, maxVal);
    int filled    = (int)roundf((clamped - minVal) / (maxVal - minVal) * barHeight);

    // Draw label + numeric value above the bar
    char header[20];
    snprintf(header, sizeof(header), "%s:%.1f%s", label, value, unit);
    k10.canvas->canvasText(header, x, y, 0xFFFFFF, k10.canvas->eCNAndENFont16, 10, true);

    // Build the bar string:  filled = '|',  empty = '.'
    char bar[barHeight + 1];
    for (int i = 0; i < barHeight; i++)
        bar[i] = (i < filled) ? '|' : '.';
    bar[barHeight] = '\0';
    k10.canvas->canvasText(bar, x, y +18 , 0x00FF88, k10.canvas->eCNAndENFont24, barHeight, true);
}

// ─────────────────────────────────────────────────────────────────────────────
void Configure_WIFI() {
    wm.resetSettings();
    wm.setConfigPortalTimeout(100);
    wm.setShowInfoErase(false);
    wm.setClass("invert");
    bool res = wm.autoConnect(WIFI_SSID_DEBUG, WIFI_PASS_DEBUG);
    if (!res) Serial.println("WiFi portal: failed to connect");
    else      Serial.println("New WiFi saved successfully");
    wm.stopConfigPortal();
}
// ─────────────────────────────────────────────────────────────────────────────

// TASKS ─────────────────────────────────────────────────────────────────────────────
// TASK: VoiceTasks
// ─────────────────────────────────────────────────────────────────────────────
void VoiceTasks(void *pvParameters) {
    while (true) {
        if (asr.isWakeUp()) {
            music.playMusic(Melodies::BA_DING, OnceInBackground);
            asr._wakeUp = false;
        }
        if (asr.isDetectCmdID(0+1)) {
            asr._isDetectCmdID = 0;
            music.playMusic(Melodies::BA_DING, OnceInBackground);
            toggleLight();
        } else if (asr.isDetectCmdID(1+1)) {
            asr._isDetectCmdID = 0;
            music.playMusic(Melodies::BA_DING, OnceInBackground);
            toggleFan();
        } else if (asr.isDetectCmdID(2+1)) {
            asr._isDetectCmdID = 0;
            music.playMusic(Melodies::BA_DING, OnceInBackground);
            toggleAC();
        }
        else if (asr.isDetectCmdID(3+1)) {
            asr._isDetectCmdID = 0;
            music.playMusic(Melodies::BA_DING, OnceInBackground);
            xSemaphoreTake(stateMutex, portMAX_DELAY);
            currentPage = PAGE_ALARM;
            xSemaphoreGive(stateMutex);
            backgroundNeedsRedraw = true;
        }
        else if (asr.isDetectCmdID(4+1)) {
            asr._isDetectCmdID = 0;
            music.playMusic(Melodies::BA_DING, OnceInBackground);
            xSemaphoreTake(stateMutex, portMAX_DELAY);
            currentPage = PAGE_MAIN;
            xSemaphoreGive(stateMutex);
            backgroundNeedsRedraw = true;
        }
        else if (asr.isDetectCmdID(5+1)) {
            asr._isDetectCmdID = 0;
            music.playMusic(Melodies::BA_DING, OnceInBackground);
            xSemaphoreTake(stateMutex, portMAX_DELAY);
            fanSpeed = 4; // full speed
            xSemaphoreGive(stateMutex);
            Serial.println("Fan set to full speed via voice command");
        }
        else if (asr.isDetectCmdID(6+1)) {
            asr._isDetectCmdID = 0;
            music.playMusic(Melodies::BA_DING, OnceInBackground);
            xSemaphoreTake(stateMutex, portMAX_DELAY);
            fanSpeed = 1; // low speed
            xSemaphoreGive(stateMutex);
            Serial.println("Fan set to low speed via voice command");
        }
        vTaskDelay(pdMS_TO_TICKS(50));
    }
}

// TASK: ButtonTasks
// ─────────────────────────────────────────────────────────────────────────────
void ButtonTasks(void *pvParameters) {
    bool prevLeftTop     = false;
    bool prevLeftBottom  = false;
    bool prevRightTop    = false;
    bool prevRightBottom = false;

    bool     lbHeld      = false;
    uint32_t lbPressTime = 0;
    bool     lbLongFired = false;

    while (true) {
        bool curLeftTop     = digital_read(LeftTopButton);
        bool curLeftBottom  = digital_read(LeftBottomButton);
        bool curRightTop    = digital_read(RightTopButton);
        bool curRightBottom = digital_read(RightBottomButton);

        bool pressedLeftTop     = curLeftTop     && !prevLeftTop;
        bool pressedLeftBottom  = curLeftBottom  && !prevLeftBottom;
        bool pressedRightTop    = curRightTop    && !prevRightTop;
        bool pressedRightBottom = curRightBottom && !prevRightBottom;
        bool releasedLeftTop = !curLeftTop &&  prevLeftTop;

        Page page;
        xSemaphoreTake(stateMutex, portMAX_DELAY);
            page = currentPage;
        xSemaphoreGive(stateMutex);
        xSemaphoreTake(DisplayMutex, portMAX_DELAY);
            uint8_t dutyCopy = duty; // make a local copy of duty for decision making to avoid holding the mutex during long operations
        xSemaphoreGive(DisplayMutex);


        //When buttons pressed
        //turn display on if it is off
        if ((pressedLeftBottom || pressedRightBottom || pressedLeftTop || pressedRightTop) && dutyCopy == 0) {
            setBacklight(maxLightIntensity); // turn on to max brightness on button press if currently off for better visibility of UI during interaction, will auto-dim after 2 seconds based on ambient light
        }
        else{
            // ── LeftBottomButton ─────────────────────────────────────────────────
            // AC functionality in main page and alarm toggle in alarm page
            if (pressedLeftBottom) {
                if (page == PAGE_MAIN) {
                    toggleAC();
                } else {
                    xSemaphoreTake(AlarmMutex, portMAX_DELAY);
                    alarmEnabled = !alarmEnabled;
                    if (alarmEnabled) alarmFired = false;  // re-arm when enabling
                    xSemaphoreGive(AlarmMutex);
                }
            }

            // ── RightBottomButton ─────────────────────────────────────────────
            // toggle fan in home page and increase minute in alarm page
            if (pressedRightBottom) {
                if (page == PAGE_MAIN) {
                    toggleFan();
                } else {
                    xSemaphoreTake(AlarmMutex, portMAX_DELAY);
                    alarmMinute = (alarmMinute + 2) % 60;
                    alarmFired  = false;   // time changed, re-arm
                    xSemaphoreGive(AlarmMutex);
                }
            }

            // ── RightTopButton ────────────────────────────────────────────────
            // toggle light in home page and increase hour in alarm page
            if (pressedRightTop) {
                if (page == PAGE_MAIN) {
                    toggleLight();
                } else {
                    xSemaphoreTake(AlarmMutex, portMAX_DELAY);
                    alarmHour = (alarmHour + 1) % 24;
                    alarmFired = false;   // time changed, re-arm
                    xSemaphoreGive(AlarmMutex);
                }
            }

            // ── LeftTopButton ──────────────────────────────────────────────
            // switch pages and alarm off in both pages with long-press and short-press respectively and speed control
            if (pressedLeftTop) {
                lbHeld      = true;
                lbPressTime = millis();
                lbLongFired = false;
            }
            //if pressed for long time, toggle page. if released before long-press threshold, toggle alarm (if on alarm page) or change fan speed (if on main page)
            if (lbHeld && curLeftTop) {
                if (!lbLongFired && (millis() - lbPressTime >= pageSwitchPressTime)) {
                    // long press, alarm was not running switch page
                    lbLongFired = true;
                    xSemaphoreTake(stateMutex, portMAX_DELAY);
                    currentPage = (currentPage == PAGE_MAIN) ? PAGE_ALARM : PAGE_MAIN;
                    xSemaphoreGive(stateMutex);
                    backgroundNeedsRedraw = true;
                    Serial.println(currentPage == PAGE_MAIN ? "Page: MAIN" : "Page: ALARM");
                }
            }
            // short press action (only if not long-pressed): toggle alarm if on alarm page, change fan speed if on main page
            if (releasedLeftTop) {
                // Dismiss alarm if running (check before page-toggle)
                xSemaphoreTake(AlarmMutex, portMAX_DELAY);
                bool running = alarmRunning;
                if (running) {
                    alarmRunning = false;   //stop alarm
                    alarmFired   = true;   // prevent re-fire this minute
                }
                xSemaphoreGive(AlarmMutex);

                //change speed of fan at short presses when fan is on.
                if (page == PAGE_MAIN && TriacFanState == true && !lbLongFired) {
                    xSemaphoreTake(stateMutex, portMAX_DELAY);
                    fanSpeed = (fanSpeed % 4) + 1;  // cycle through 1,2,3,4 (0 is off, 4 is full on)
                    xSemaphoreGive(stateMutex);
                }

                lbHeld = false;
            }


            // ── enter config mode ─────────────────────────────────────────────
            if (pressedLeftBottom && pressedRightBottom) {
                music.playMusic(Melodies::BA_DING, OnceInBackground);
                Serial.println("Entering OTA Mode");
                Configure_WIFI();       //enable WiFi and block here until new credentials are entered
            }
        }

        prevLeftTop     = curLeftTop;
        prevLeftBottom  = curLeftBottom;
        prevRightTop    = curRightTop;
        prevRightBottom = curRightBottom;
        
        //Fan control
        //vTaskDelay(pdMS_TO_TICKS(20));
        xSemaphoreTake(stateMutex, portMAX_DELAY);
        bool triacfanstatee = TriacFanState;
        uint8_t fanspeede = fanSpeed;
        xSemaphoreGive(stateMutex);
        // Run fan speed control in button task for more responsive control since it uses timing-based control
        if(triacfanstatee){
            RunFanSpeed(fanspeede);  // from speed 1 to 4
        }
        else{
            RunFanSpeed(0); // fully off
        }
    }
}

//Task: AlarmTasks
// ─────────────────────────────────────────────────────────────────────────────
void AlarmTasks(void *pvParameters) {
    struct tm timeinfo;          // local copy, not shared
    bool alarmSoundActive = false; // local to this task — no race
    while (true) {
        bool timeOkk = false;
        if(WiFi.status() == WL_CONNECTED) {
            timeOkk = getLocalTime(&timeinfo, 0);  // ← 0ms timeout, never blocks
        }

        // ── Snapshot alarm state ──────────────────────────────────────────
        //Serial.println("AlarmTasks: Checking alarm...");
        xSemaphoreTake(AlarmMutex, portMAX_DELAY);
        int  aHour    = alarmHour;
        int  aMin     = alarmMinute;
        bool aEnabled = alarmEnabled;
        bool aFired   = alarmFired;
        bool aRunning = alarmRunning;
        xSemaphoreGive(AlarmMutex);

        //serial print for debugging alarm logic
        Serial.printf("Alarm check: timeOk=%d enabled=%d fired=%d running=%d "
        "now=%02d:%02d alarm=%02d:%02d sound=%d\n",
        timeOkk, aEnabled, aFired, aRunning,
        timeinfo.tm_hour, timeinfo.tm_min,
        aHour, aMin, alarmSoundActive);

        // ── Check alarm ───────────────────────────────────────────────────
          static uint32_t alarmStartMs = 0;

        if (aEnabled && timeOkk && !aFired && !aRunning &&
            timeinfo.tm_hour == aHour && timeinfo.tm_min == aMin) {
            xSemaphoreTake(AlarmMutex, portMAX_DELAY);
            alarmRunning = true;
            xSemaphoreGive(AlarmMutex);
            aRunning = true;
            alarmStartMs = millis();
        }

        // auto-stop after the duration
        if (aRunning && millis() - alarmStartMs >= (uint32_t)alarmDurationMins * 60000UL) {
            xSemaphoreTake(AlarmMutex, portMAX_DELAY);
            alarmRunning = false;
            alarmFired = true;
            xSemaphoreGive(AlarmMutex);
            aRunning = false;
        }

        // re-arm once the clock leaves the alarm minute
        if (aFired && timeOkk && (timeinfo.tm_hour != aHour || timeinfo.tm_min != aMin)) {
            xSemaphoreTake(AlarmMutex, portMAX_DELAY);
            alarmFired = false;
            xSemaphoreGive(AlarmMutex);
        }
        vTaskDelay(pdMS_TO_TICKS(200));
    }
}
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
void loop() {
 vTaskDelay(pdMS_TO_TICKS(10));
}

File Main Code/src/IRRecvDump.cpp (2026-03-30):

//this code is use to dump the raw data of the IR signal received by the IR receiver, and then we can use this data to decode the signal and find out which button is pressed on the remote control. This code is based on the IRrecvDump example provided by the IRremoteESP8266 library, but it has been modified to work with the ESP32-C3 and to use a larger capture buffer size and a longer timeout value to capture more complex messages. The code also includes some tunable parameters that can be adjusted to improve the accuracy of the decoding process.
//this is not the part pf the main code.
//ignore this code

// #include <Arduino.h>
// #include <assert.h>
// #include <IRrecv.h>
// #include <IRremoteESP8266.h>
// #include <IRac.h>
// #include <IRtext.h>
// #include <IRutils.h>

// // ==================== start of TUNEABLE PARAMETERS ====================
// // An IR detector/demodulator is connected to GPIO pin 14
// // e.g. D5 on a NodeMCU board.
// // Note: GPIO 16 won't work on the ESP8266 as it does not have interrupts.
// // Note: GPIO 14 won't work on the ESP32-C3 as it causes the board to reboot.
// const uint16_t kRecvPin = 23;


// // The Serial connection baud rate.
// // i.e. Status message will be sent to the PC at this baud rate.
// // Try to avoid slow speeds like 9600, as you will miss messages and
// // cause other problems. 115200 (or faster) is recommended.
// // NOTE: Make sure you set your Serial Monitor to the same speed.
// const uint32_t kBaudRate = 115200;

// // As this program is a special purpose capture/decoder, let us use a larger
// // than normal buffer so we can handle Air Conditioner remote codes.
// const uint16_t kCaptureBufferSize = 1024;

// // kTimeout is the Nr. of milli-Seconds of no-more-data before we consider a
// // message ended.
// // This parameter is an interesting trade-off. The longer the timeout, the more
// // complex a message it can capture. e.g. Some device protocols will send
// // multiple message packets in quick succession, like Air Conditioner remotes.
// // Air Coniditioner protocols often have a considerable gap (20-40+ms) between
// // packets.
// // The downside of a large timeout value is a lot of less complex protocols
// // send multiple messages when the remote's button is held down. The gap between
// // them is often also around 20+ms. This can result in the raw data be 2-3+
// // times larger than needed as it has captured 2-3+ messages in a single
// // capture. Setting a low timeout value can resolve this.
// // So, choosing the best kTimeout value for your use particular case is
// // quite nuanced. Good luck and happy hunting.
// // NOTE: Don't exceed kMaxTimeoutMs. Typically 130ms.
// #if DECODE_AC
// // Some A/C units have gaps in their protocols of ~40ms. e.g. Kelvinator
// // A value this large may swallow repeats of some protocols
// const uint8_t kTimeout = 50;
// #else   // DECODE_AC
// // Suits most messages, while not swallowing many repeats.
// const uint8_t kTimeout = 15;
// #endif  // DECODE_AC
// // Alternatives:
// // const uint8_t kTimeout = 90;
// // Suits messages with big gaps like XMP-1 & some aircon units, but can
// // accidentally swallow repeated messages in the rawData[] output.
// //
// // const uint8_t kTimeout = kMaxTimeoutMs;
// // This will set it to our currently allowed maximum.
// // Values this high are problematic because it is roughly the typical boundary
// // where most messages repeat.
// // e.g. It will stop decoding a message and start sending it to serial at
// //      precisely the time when the next message is likely to be transmitted,
// //      and may miss it.

// // Set the smallest sized "UNKNOWN" message packets we actually care about.
// // This value helps reduce the false-positive detection rate of IR background
// // noise as real messages. The chances of background IR noise getting detected
// // as a message increases with the length of the kTimeout value. (See above)
// // The downside of setting this message too large is you can miss some valid
// // short messages for protocols that this library doesn't yet decode.
// //
// // Set higher if you get lots of random short UNKNOWN messages when nothing
// // should be sending a message.
// // Set lower if you are sure your setup is working, but it doesn't see messages
// // from your device. (e.g. Other IR remotes work.)
// // NOTE: Set this value very high to effectively turn off UNKNOWN detection.
// const uint16_t kMinUnknownSize = 12;

// // How much percentage lee way do we give to incoming signals in order to match
// // it?
// // e.g. +/- 25% (default) to an expected value of 500 would mean matching a
// //      value between 375 & 625 inclusive.
// // Note: Default is 25(%). Going to a value >= 50(%) will cause some protocols
// //       to no longer match correctly. In normal situations you probably do not
// //       need to adjust this value. Typically that's when the library detects
// //       your remote's message some of the time, but not all of the time.
// const uint8_t kTolerancePercentage = kTolerance;  // kTolerance is normally 25%

// // Legacy (No longer supported!)
// //
// // Change to `true` if you miss/need the old "Raw Timing[]" display.
// #define LEGACY_TIMING_INFO false
// // ==================== end of TUNEABLE PARAMETERS ====================

// // Use turn on the save buffer feature for more complete capture coverage.
// IRrecv irrecv(kRecvPin, kCaptureBufferSize, kTimeout, true);
// decode_results results;  // Somewhere to store the results

// // This section of code runs only once at start-up.
// void setup() {
//     Serial.begin(kBaudRate);
//   while (!Serial)  // Wait for the serial connection to be establised.
//     delay(50);
//   // Perform a low level sanity checks that the compiler performs bit field
//   // packing as we expect and Endianness is as we expect.
//   assert(irutils::lowLevelSanityCheck() == 0);

//   Serial.printf("\n" D_STR_IRRECVDUMP_STARTUP "\n", kRecvPin);
// #if DECODE_HASH
//   // Ignore messages with less than minimum on or off pulses.
//   irrecv.setUnknownThreshold(kMinUnknownSize);
// #endif  // DECODE_HASH
//   irrecv.setTolerance(kTolerancePercentage);  // Override the default tolerance.
//   irrecv.enableIRIn();  // Start the receiver
// }
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

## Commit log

2026-03-22 IR AC control with button wokrs!
2026-03-23 light fan control added
2026-03-25 bugs fixed, alarm added
    [partitions.csv]
2026-03-25 EEverything working except backlight pin crashes with voice
    [Main.cpp]
2026-03-26 backlight added, wifi issue fixed, everything works!
    [Main.cpp]
2026-03-27 IR issue & bugs fixed
    [IRSendBasic.cpp, Main.cpp]
2026-03-30 circuit, graphics, stl, Resources added
    [Main body body.stl, Main circuit V1.0.kicad_pcb, Main circuit V1.0.kicad_sch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]
2026-03-30 display bug and some other fixed
    [IRRecvDump.cpp, IRSendBasic.cpp, Main.cpp]
2026-04-03 fan speed, alarm timeout added
    [Main circuit V1.0.kicad_sch]
2026-04-04 Details and images added
    [Main body body.stl, main body front.stl]
2026-04-10 fan speed bug fixed
    [Main.cpp]
2026-05-25 bug fix
    [partitions.csv]
2026-05-29 Fix bug in readALS() function and update README
    Added a bug fix for the readALS() function in Unihikerk10.cpp to prevent device reset in complete darkness. Updated project details and features.
2026-06-09 backlight turn on issue fix
    [Main.cpp]
2026-10-02 display refresh and alarm bug fix
    [Main.cpp]
